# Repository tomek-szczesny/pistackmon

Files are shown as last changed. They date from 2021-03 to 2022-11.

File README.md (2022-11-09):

# PiStackMon

## What is it?

PiStackMon started off as a hardware module for distributing power to multiple stacked Raspberry Pi computers, rathen than handling multiple USB power adapters.

Over time, with its feature list open for new ideas, it grew into a highly integrated, multi purpose board with extended connectivity options.

The most eye catching feature is the live system monitor, with three most basic parameters (Temperature, RAM and CPU) clearly presented on a LED matrix. This helps quickly diagnosing performance bottlenecks by just looking at your cluster. LEDs are driven by a lightweight daemon, *pistackmond*, that compiles and runs on any target architecture.

PiStackMon comes with a variety of extra connectivity features, such as optically isolated outputs, isolated high current switches (up to 6A), dedicated fan output with suitable transistor, not to mention the usual I2C, UART or SPI.

Finally, PiStackMon allows you to power your SBC via GPIO pins, with additional polyfuse protection and a large capacitor, ensuring safe and stable operation. Screw terminals or barrel jack power inputs let you use any 5V power supply you wish, or even daisy chain a few units, thus sharing a common supply.

PiStackMon is compatible with any SBC following the RasPi GPIO layout. 

## Hardware

PiStackMon comes in two varieties, *lite* and *classic*.

### PiStackMon Lite

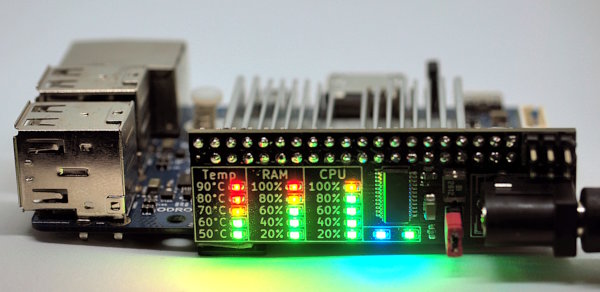
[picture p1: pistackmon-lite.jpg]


By popular demand, a new hardware version has been rolled out, offering the most useful subset of features seen in the Classic design. All mandatory SMD components are placed on top side, so the board may be ordered preassembled by JLCPCB. All required files are available in this repository.

The user is required to solder their own 40-pin socket, power switch pin header and power socket of their choice.

Features include:

- DC power input (either 5mm screw terminal or barrel jack)

- 2.5A Polyfuse protection

- 100uF ceramic capacitor

- Pin header for managing power supply (using a jumper or any other mechanical switch)

- 3x 5-LED indicators of real-time CPU usage, RAM usage and CPU temperature

- +5V LED indicator

- Extra user-programmable LED

- Soldering pads for accesing selected GPIOs:
  
  - I2C1
  
  - UART
  
  - GND, 3V3

- Two 0805 SMD placeholders for optional I2C1 pullup resistors

### PiStackMon Classic

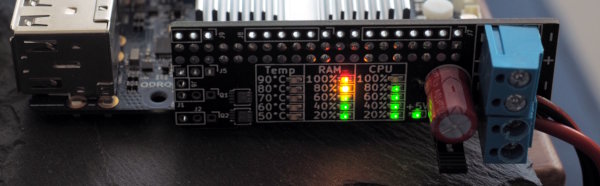
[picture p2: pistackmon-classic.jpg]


The omnipotent, original design with all features available in the project. It is targeted at more advanced users, as no kits or preassembled units are available.

Alternatively, the schematic and KiCAD project files are available for reference. Feel free to modify it to suit your needs!

The design follows strict rules, so PCBs may be obtained for as low as 2 USD per 5 pieces at JLCPCB. 

- Supplying SBCs via screw terminals rather than USB port

- Dual power inputs-outputs allow clean and easy daisy-chaining

- 2.5A self-healing polyfuse protection 

- Bulk capacitor helps preventing transient undervoltage events

- Pin header for managing power supply (using a jumper or any other mechanical switch)

- +5V LED indicator

- 3x 5-LED indicators of real-time CPU usage, RAM usage and CPU temperature

- Auxiliary IOs for your projects:
  
  - SPI0, I2C1 and 1Wire easily accesible through 2.54mm headers
  
  - 1-Wire pullup resistor
  
  - 3-pin header with RC-filtered 3V3 supply for IR sensors
  
  - 2-pin header with 5V and BJT-reinforced low side switch, for PWM fan control
  
  - Two optically isolated outputs, for pulling external logic up or down (>2.5mA)
  
  - Two high-power, isolated low side switches, up to 26V and 6A
  
  - Alternatively, MCP1416s can be used as line drivers directly
  
  - Optical isolation lets you drive external circuits without creating ground loops
  
  - One isolated output and one high-power switch are connected to hardware PWM GPIO pins

- Low profile PCBs allow stacking with spacers as short as 20mm,

- No risk of contact with conductive stack spacers

- Components selected for low cost and relatively easy assembly (One TSSOP24 chip might be tricky)

- Alternative components are listed as well

- Modular design lets you build even cheaper boards without features you don't need

## Software

*pistackmond* is a lightweight daemon that's only purpose is to read system stats and drive PiStackMon LEDs. Additionally, it may be used by external software to drive the user-programmable LED available in PiStackMon Lite.

The recommended way to set up *pistackmond* on a target machine is to build it from source, in a few simple steps explained below. Alternatively, a DEB package may be built and distributed within your cluster.

*pistackmond* runs as a systemd service and has no dependencies outside standard C++ libraries. It has been tested on multiple Linux systems, including those based on Ubuntu, Debian or Arch.

#### Building pistackmond from source

- Log in to your SBC as any user with sudo access. 

- Install `git`, `g++` and `make`:
  
  - Debian, Ubuntu, RasPi OS etc:
    
    `sudo apt install git g++ make`
  
  - Arch, Manjaro and other derivatives:
    
    `sudo pacman -S git gcc make`

- Clone this repository:
  
  `git clone --depth 1 --branch main https://github.com/tomek-szczesny/pistackmon.git`

- Enter sw directory:
  
  - `cd pistackmon/sw`

- List build options to pick the right one for your SBC:
  
  - `make`

- Build pistackmond (Example for Raspberry Pi 4):
  
  - `make rpi4`

- Install and run systemd service
  
  - `sudo make install`

Note that you can change the default-brightness of LED-colors using the make
command, e.g. the following command changes the default 0.35 to 0.25.

    make rpi4 LED_G=0.25

The executable `pistackmond` supports various commandline arguments, see

    pistackmond -h

for a short help. Typically it is used to control the user-led (light version
only):

    pistackmond -u 1
    pistackmond -u 0
    pistackmond -u 0.4

The first command turns the blue user-led on, the second off and the third
turns it on with reduced brightness.

The `-b` option is used as a scaling factor for the overall brightness and
is only valid during service-startup. To set the factor for the service,
edit `/etc/default/pistackmond`.

That's it! PiStackMon should start displaying your computer stats immediately.

#### Creating a DEB-Package

In case you don't want to have a compiler and source code on your
production machines, you can create a deb-package on one system and
install it on multiple other systems.

The recommended procedure is:

```
apt-get -y install checkinstall  # if not already installed
cd pistackmon/sw
make clean                       # in case you don't start from scratch
#edit the `makefile` and replace `PREFIX=/usr/local` with `PREFIX=/usr`
make rpi4
sudo ./make-deb rpi4
```

This will create a package named `pistackmond-rpi4...deb`.

To install this package, run

```
dpkg -i pistackmond-rpi4...deb
sudo systemctl start pistackmond.service
```

## Compatible SBCs

PiStackMon is electrically compatible with all SBCs that follow the RasPi 40-pin GPIO layout. However, explicit support must be implemented in *pistackmond* daemon for that to work.

| SBC | Status | Remarks |
| --- | --- | --- |
| Raspberry Pi 3 | Compatible | |
| Raspberry Pi 4 | Compatible | |
| Odroid N2(+)(L)| Compatible | Powering via PiStackMon is not supported. Any attempt will likely destroy your N2. |
| Odroid C1(+) | Compatible | Temperature sensing not confirmed. OS must export CPU temperature to the following file: `/sys/devices/virtual/thermal/thermal_zone0/temp` |
| Odroid C2 | Compatible | Powering via PiStackMon may be possible - not tested, proceed with caution. |
| Odroid M1 | Compatible | Powering via PiStackMon is not supported. Any attempt will likely destroy your M1. |

Limited amount of free PiStackMon samples is available for testers and contributors for new platforms. Open an Issue to get in touch!

# Disclaimer

This hardware and software is provided as-is.
All hardware and software presented in this repository may pose hazard to humans, animals, plants, fungi, ghosts, spirits and hardware, and is not guaranteed to work at all.
DO NOT ATTEMPT TO MAKE ANY USE OF FILES PROVIDED IN THIS REPOSITORY.

Users agree to take full responsibility for their actions involving files in this repository.
Ask an expert before you mess with stuff you don't understand.

# 

# Building PistackMon Classic

This chapter will definitely need some love, but for now just be sure to follow a few guidelines off the top of my head:

- Decide which features you need or not. As a rule of thumb, you may ignore any boxed part of a schematic independently.
- Check the datasheet of your LEDs or experiment to determine what is the optimal driving current for them. Some LEDs need 1mA, some 10mA. There are no recommended LEDs for PiStackMon.
- If different colors of your LEDs of choice have different intensities, don't worry, there are const values in the code to compensate for that.
- "NM" resistors are simply Not Mounted - leave these places empty, unlesss you want to hack PiStackMon for other purposes.
- Before you do anything, just remember that 40-pin connector should be mounted as the very last component, after you make sure everything else works. Consider it a permanent component, because removing it is indeed a pain in the rectum.
- Mount everything you plan to include, except 40-pin connector and C1. Power up your SBC using its original power input. You may test PiStackMon by carefully connecting it to SBC's GPIO header directly, and applying some tension to ensure proper connection. It is a good idea to check if all LEDs work correctly and that you picked the right LED currents.
- After soldering, make sure you clean your board _very carefully_ from any traces of flux, especially under and around the LED driver chip. Dip it in pure alcohol for an hour if you have to. Failing to do so may make some LEDs glow even though these are supposed to be off.
- Place a tiny heatsink on a low side high-power switch MOSFET if you plan to thrash the living hell out of it.

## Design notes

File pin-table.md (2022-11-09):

Pin-Table
=========

This table just documents the pins for the various supported boards.
Numbers in parenthesis are libgpiod-line numbers.

Pin   |Physical | Pi3/Pi4 |  N2(+)(L) |   C1(+)       |  C2  |  M1 (numbers to be verified) |
------|---------|---------|-----------|---------------|------|------------------------------|
DATA  |      11 |      17 |  X.3 (69) |  88  Y.8 (23) | X.19 | 0C.0 (16)                    |
CLK   |      13 |      27 |  X.4 (70) | 116 X.19 (15) | X.11 | 0C.1 (17)                    |
LATCH |      15 |      22 |  X.7 (73) | 115 X.18 (14) | X.9  | 3B.2 (106)                   |
BLANK |      22 |      25 |  X.2 (68) | 103 X.6  ()   | X.3  | 3D.1 (121)                   |

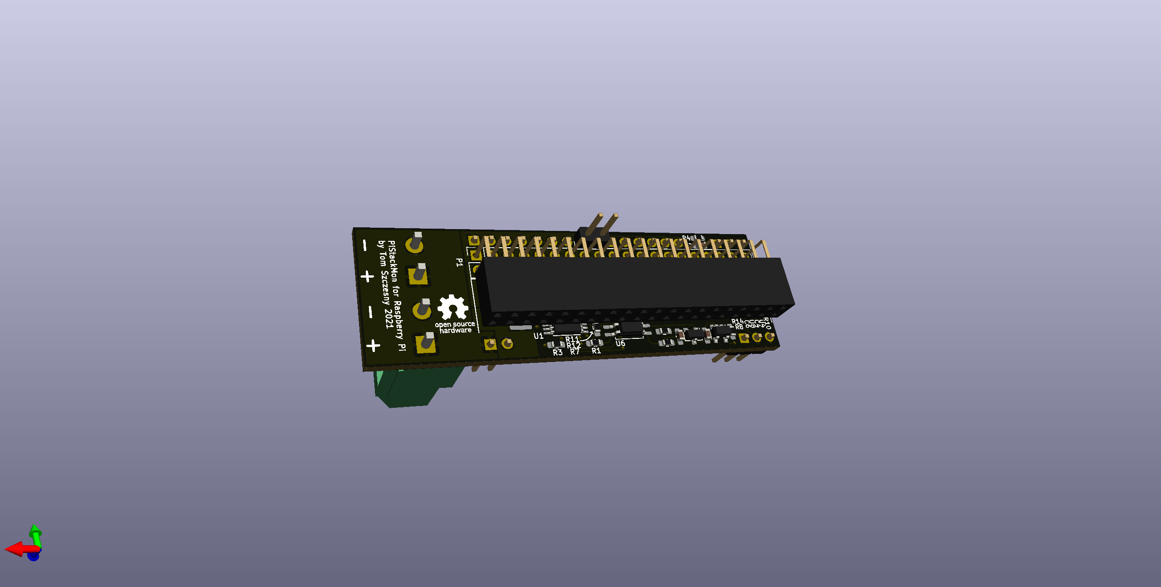
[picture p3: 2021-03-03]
hw/classic/pdfs/PiStackMon_back.png

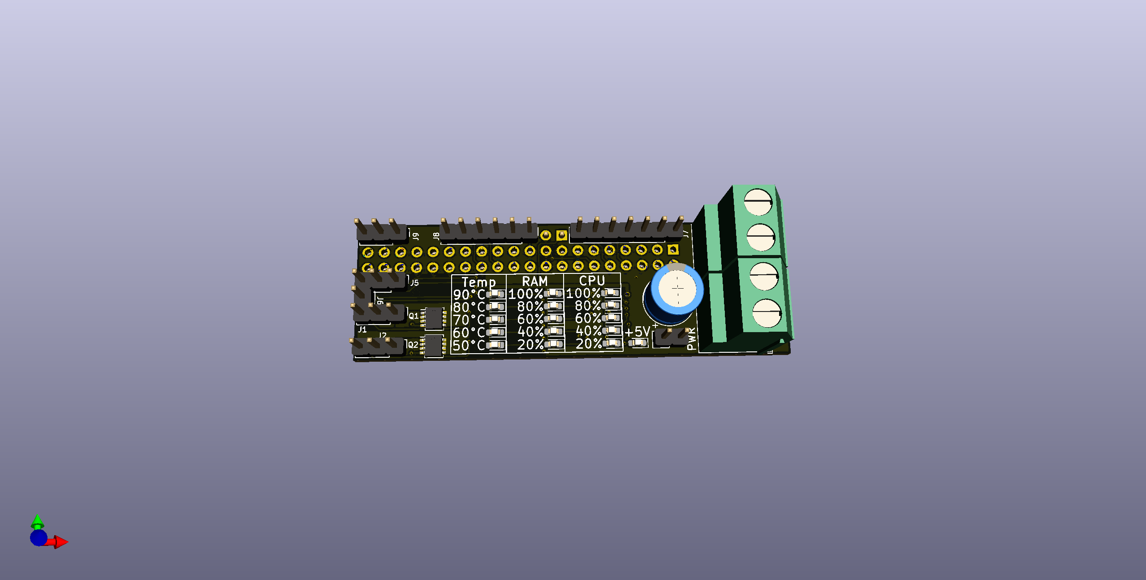
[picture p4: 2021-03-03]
hw/classic/pdfs/PiStackMon.png

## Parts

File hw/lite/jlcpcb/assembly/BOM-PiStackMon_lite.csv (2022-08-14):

Comment | Designator | Footprint | LCSC
TLC59282DBQR | U1 | SSOP-24_3.9x8.7mm_P0.635mm | C129352
100u 6.3V | C1 | C_1206_3216Metric | C15008
100n | C2 | C_0402_1005Metric | C1525
1k8 | R3 | R_0603_1608Metric | C4177
27k | R2 | R_0603_1608Metric | C22967
3k3 | R5 | R_0402_1005Metric | C25890
SMD1812B260TF/12 | F1 | Fuse_1812_4532Metric | C269147
Y | D13,D5,D9 | LED_0603_1608Metric | C72038
B | D17 | LED_0603_1608Metric | C72041
G | D1,D14,D15,D16,D2,D3,D4,D6,D7,D8 | LED_0603_1608Metric | C72043
R | D10,D11,D12 | LED_0603_1608Metric | C72044

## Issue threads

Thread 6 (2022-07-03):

pistackmond crashes immediately after previous instance terminated with sigkill

tomek-szczesny, 2022-07-03:
After pistackmond has been terminated non-gracefully (with sigkill), it appears the shared memory file still exists and stands in the way.
Sudoer can remove this file and later everything works as expected.

I'm not sure whether pistackmond should check if shared memory file exists and if so, maybe try deleting it. If that succeeds, then it means there is no other pistackmond process that keeps this file open. I'm just speculating here and would appreciate your input, @bablokb. Thanks!

```
mctom@odroidm1:~/git/pistackmon/sw$ sudo systemctl status pistackmond.service
● pistackmond.service - PiStackMon Daemon
     Loaded: loaded (/etc/systemd/system/pistackmond.service; enabled; vendor preset: enable>
     Active: failed (Result: exit-code) since Sun 2022-07-03 13:52:14 CEST; 31s ago
    Process: 3353 ExecStart=/usr/local/sbin/pistackmond (code=exited, status=3)
   Main PID: 3353 (code=exited, status=3)

lip 03 13:52:14 odroidm1 systemd[1]: Started PiStackMon Daemon.
lip 03 13:52:14 odroidm1 pistackmond[3353]: shm_open failed: File exists
lip 03 13:52:14 odroidm1 systemd[1]: pistackmond.service: Main process exited, code=exited, >
lip 03 13:52:14 odroidm1 systemd[1]: pistackmond.service: Failed with result 'exit-code'.
...skipping...
● pistackmond.service - PiStackMon Daemon
     Loaded: loaded (/etc/systemd/system/pistackmond.service; enabled; vendor preset: enable>
     Active: failed (Result: exit-code) since Sun 2022-07-03 13:52:14 CEST; 31s ago
    Process: 3353 ExecStart=/usr/local/sbin/pistackmond (code=exited, status=3)
   Main PID: 3353 (code=exited, status=3)

lip 03 13:52:14 odroidm1 systemd[1]: Started PiStackMon Daemon.
lip 03 13:52:14 odroidm1 pistackmond[3353]: shm_open failed: File exists
lip 03 13:52:14 odroidm1 systemd[1]: pistackmond.service: Main process exited, code=exited, >
lip 03 13:52:14 odroidm1 systemd[1]: pistackmond.service: Failed with result 'exit-code'.
```

bablokb, 2022-07-03:
Oh yes. The service creates the shared memory and therefore is also responsible for the deletion. I will fix this. The signal-handler are already in place.

bablokb, 2022-07-03:
Should be fixed with commit 491d5954197e8289864cbb2f41f7fcfb871be11b

bablokb, 2022-07-05:
> I don't think we should handle more signals, actually SIGKILL was very handy to kill pistackmond when I made it to loop infinitely by mistake. All the other signals got caught and waited for PWM thread to finish, which unfortunately was looped forever.

We can't trap SIGKILL anyhow.

> Ideally, pistackmond should give up and exit if it finds evidence of another instance already running. Otherwise, create the shared memory file or reuse the existing one (with any value already stored in there). I hope you agree this is the best scenario. :)
>
> In bash world, I'd check if this command returns more than "1": `ps aux | grep pistackmond | grep root | wc -l` But perhaps more elegant solution exists in C++, can't tell really.

I think there is something more elegant in bash too ;-) (e.g. using -u and -C options of ps). But the main point is: does it make sense to blow up the code to catch a border-case which typically will only happen on a developer-machine?

So basically we have a few options:

  - *No change to the code, i.e. do nothing*. In this case pistackmond just won't start a second time because it assumes a running service. Normally this should be correct. If root is SIGKILLing the process, root should also remove the shm.
  - *Reuse the existing shm*. This could lead to two running services, but only if at least one of the pistackmond-executables is started manually. If you start via systemctl this should always be safe.

The caveat of the second option is the case where a user wants to set the user-led and just forgets to add the necessary parameter. But since we want to add cmdline options anyhow, we could add the option `-s` as a prereq for starting the service.

So I would suggest to leave the code as is for now. After adding cmdline-options, then we could switch to reusing the shm if it already exists. I feel no pity if someone afterwards explicitly starts the service twice.

tomek-szczesny, 2022-07-05:
Yeah, I guess you're right, it's not critical by any means. If it was fixable with 5 lines of code that would be worth consideration, but otherwise I guess we can assume the service protects against running two instances.

> The caveat of the second option is the case where a user wants to set the user-led and just forgets to add the necessary parameter.

If run as non-root user it will crash anyway. There is a TODO in the code to catch that and yell at the user instead ;)

bablokb, 2022-07-05:
Good. So I will now merge the user_led branch into main, then start with a new branch for the cmdline-options. Once this is in place I will switch the behavior to reuse the shm.

tomek-szczesny, 2022-07-05:
Excellent.
I'm leaving for Masters of Rock festival tomorrow morning so I won't be too responsive for the following week. :)

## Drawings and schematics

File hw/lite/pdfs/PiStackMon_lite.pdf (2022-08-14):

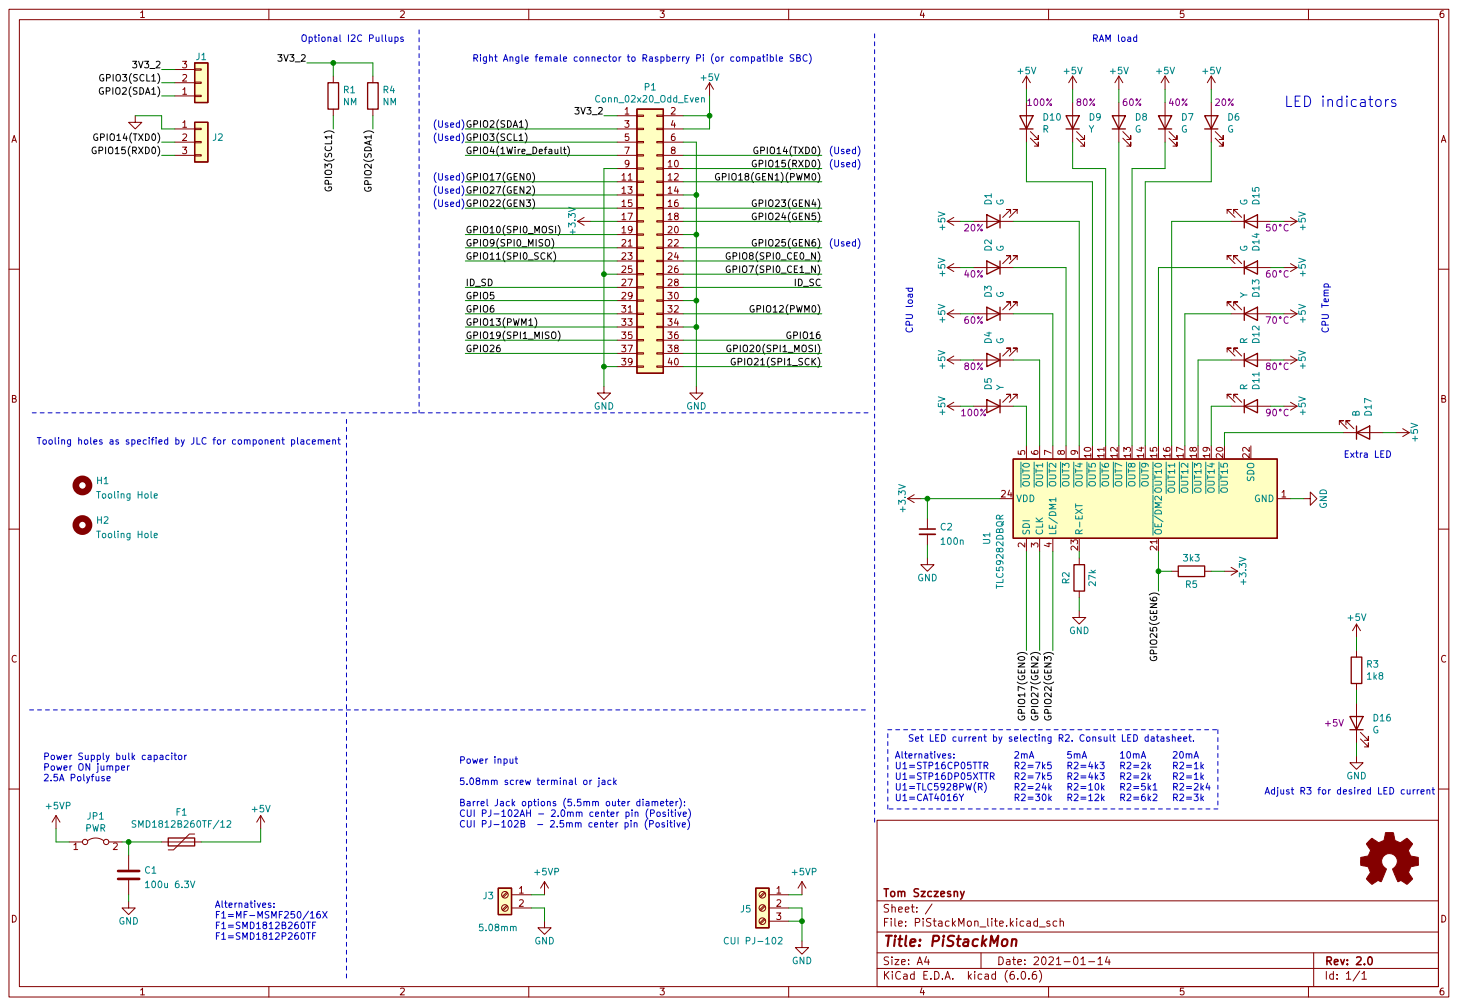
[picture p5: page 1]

Tooling holes as specified by JLC for component placement

Set LED current by selecting R2. Consult LED datasheet.
5mA R2=4k3 R2=4k3 R2=10k R2=12k Alternatives: U1=STP16CP05TTR

Power Supply bulk capacitor
Power ON jumper
2.5A Polyfuse

5.08mm screw terminal or jack

Barrel Jack options (5.5mm outer diameter):
CUI PJ-102AH - 2.0mm center pin (Positive)

File: PiStackMon_lite.kicad_sch Sheet: / Tom Szczesny

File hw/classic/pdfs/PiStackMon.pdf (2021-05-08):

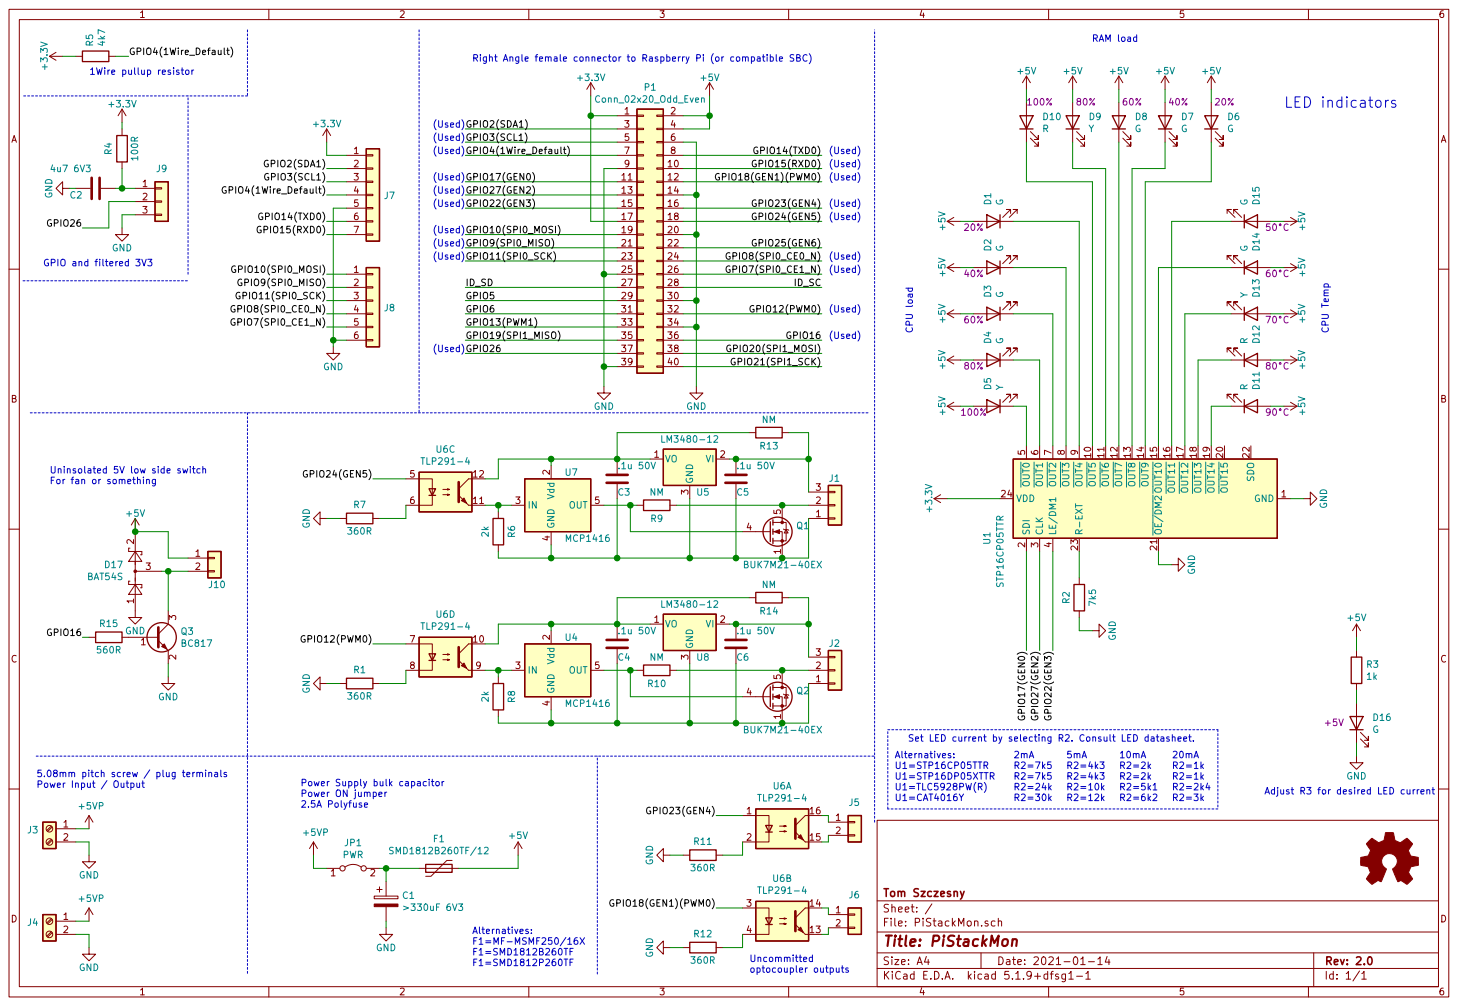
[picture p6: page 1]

Right Angle female connector to Raspberry Pi (or compatible SBC)
GPIO2(SDA1) GPIO6 GPIO5
GPIO3(SCL1)
GPIO4(1Wire_Default)

(Used) GPIO and filtered 3V3

(Used) Uninsolated 5V low side switch For fan or something

5.08mm pitch screw / plug terminals

Power Supply bulk capacitor
Power ON jumper
2.5A Polyfuse

Adjust R3 for desired LED current

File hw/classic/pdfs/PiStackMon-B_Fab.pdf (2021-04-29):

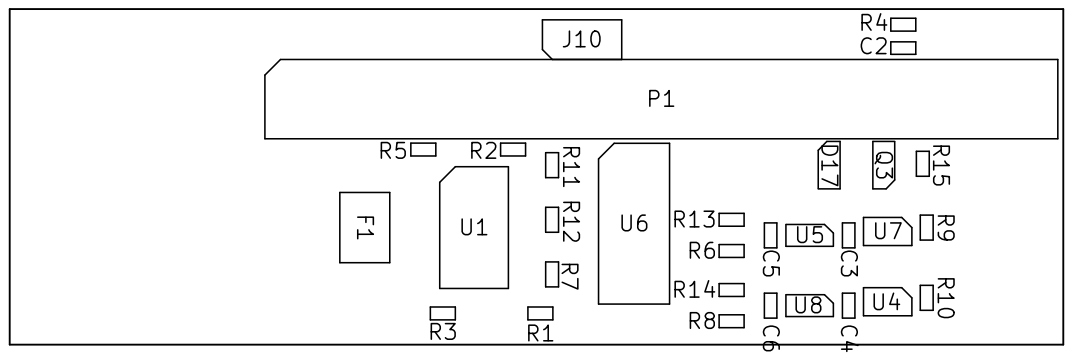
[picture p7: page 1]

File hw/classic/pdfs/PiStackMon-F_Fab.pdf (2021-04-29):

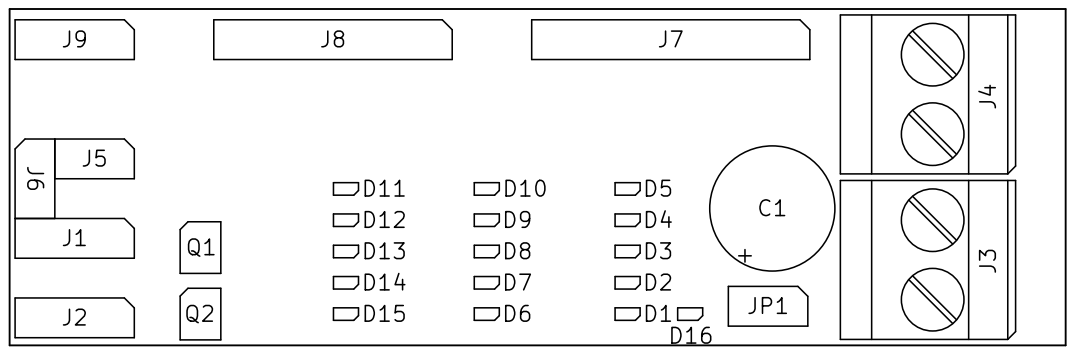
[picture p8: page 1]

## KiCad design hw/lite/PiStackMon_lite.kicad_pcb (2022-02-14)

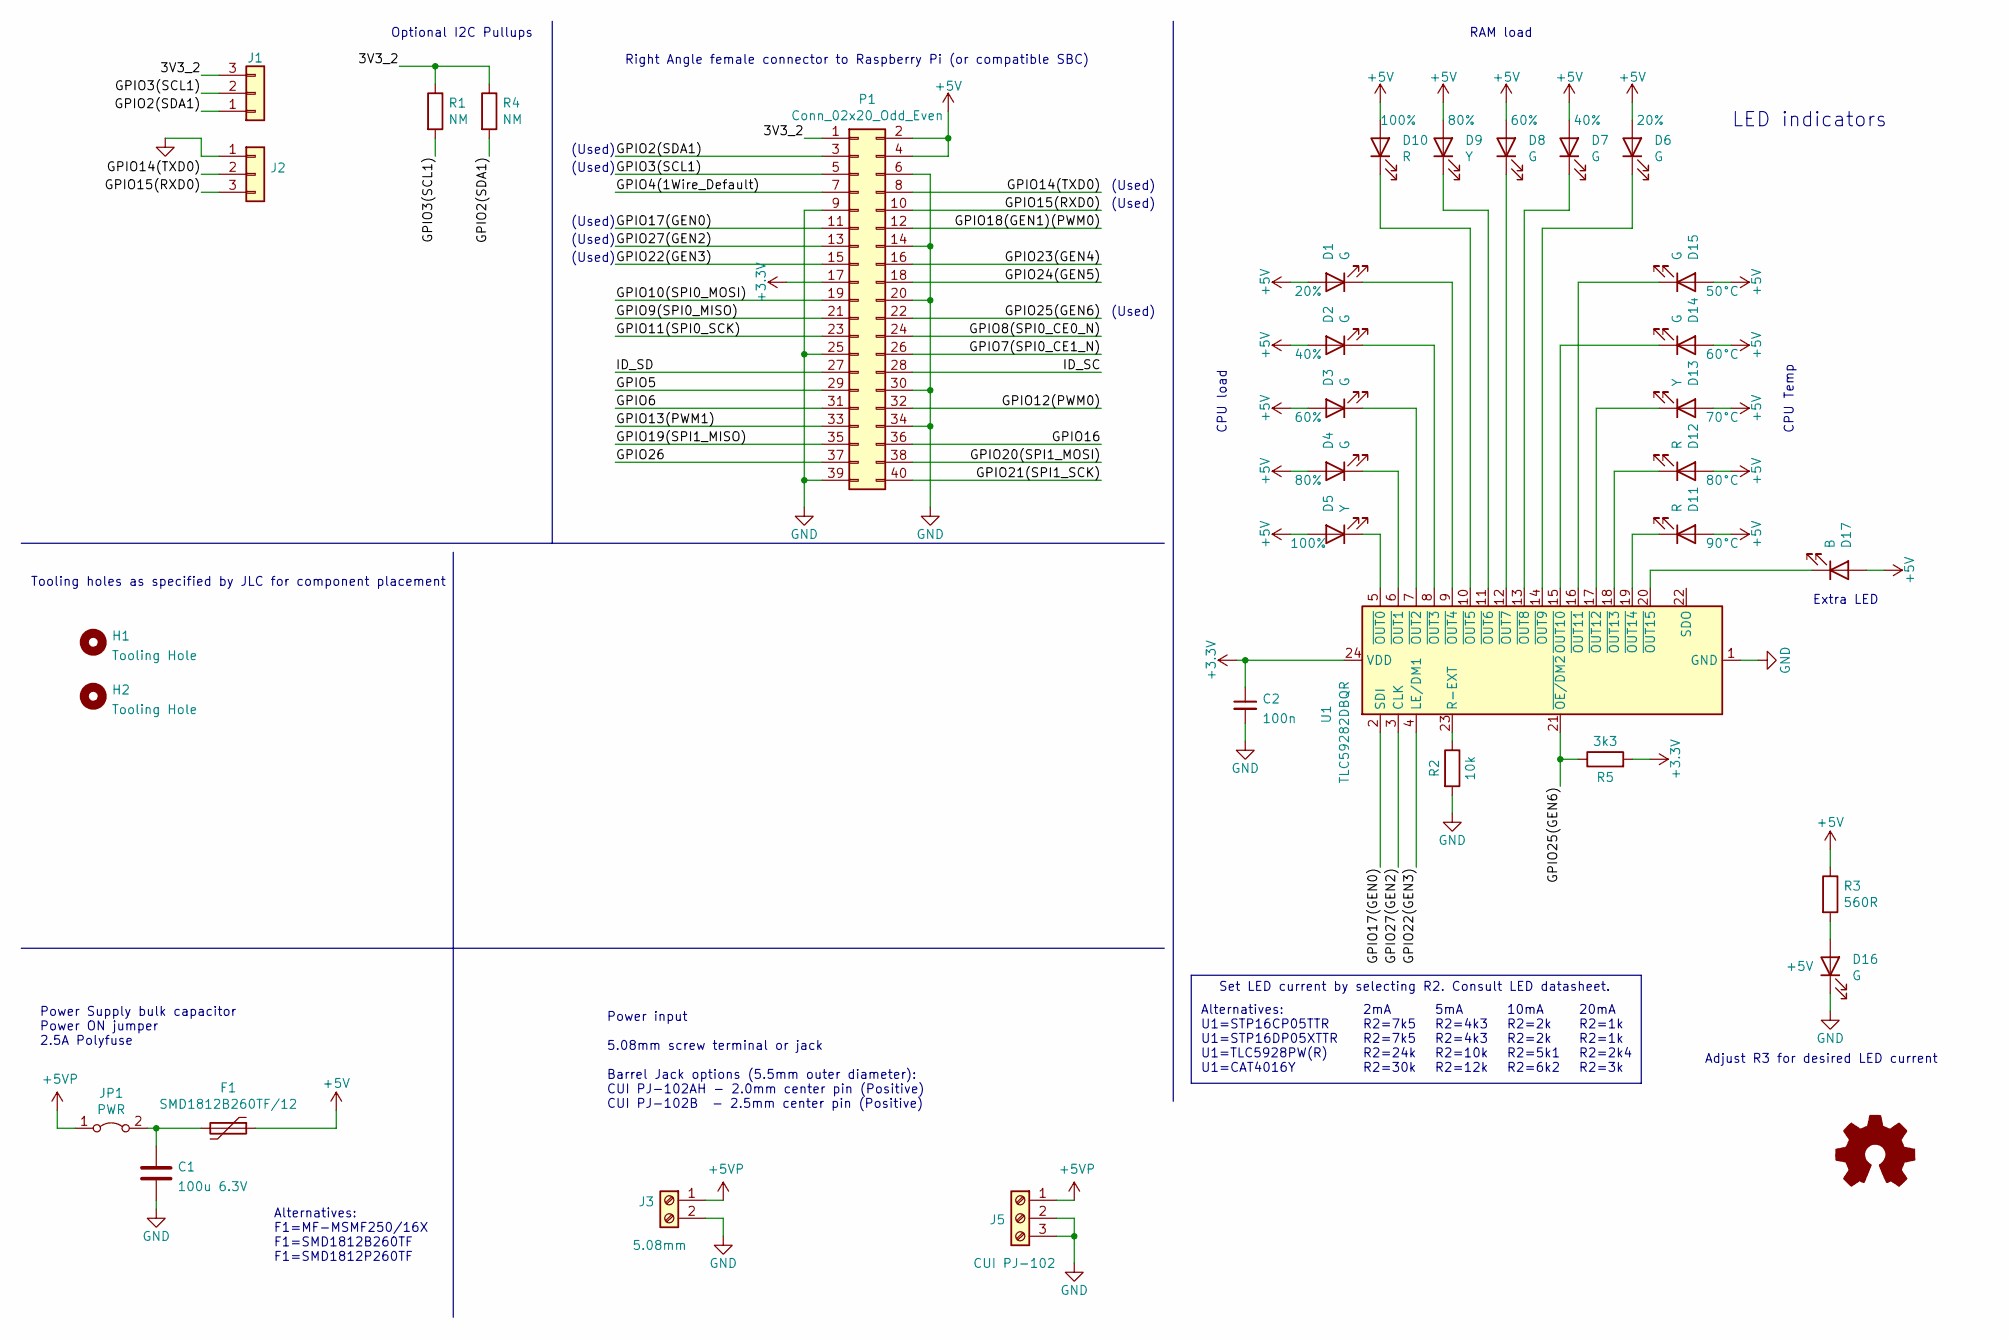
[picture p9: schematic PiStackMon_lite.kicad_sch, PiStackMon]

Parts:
C1: 100u 6.3V; C_1206_3216Metric; JLC 1206
C2: 100n; C_0402_1005Metric; LCSC C1525
D1, D2, D3, D4, D6, D7, D8, D14, D15, D16: G; LED_0603_1608Metric; LCSC C72043
D5, D9, D13: Y; LED_0603_1608Metric; LCSC C72038
D10, D11, D12: R; LED_0603_1608Metric; LCSC C72044
D17: B; LED_0603_1608Metric; LCSC C72041
F1: SMD1812B260TF/12; Fuse_1812_4532Metric; LCSC C269147
H1, H2: Tooling Hole
J1, J2: Conn_01x03; PinHeader_1x03_P2.54mm_Vertical
J3: 5.08mm; TerminalBlock_Phoenix_MKDS-3-2-5.08_1x02_P5.08mm_Horizontal
J5: CUI PJ-102; BarrelJack_CUI_PJ-102AH_Horizontal
JP1: PWR; PinHeader_1x02_P2.54mm_Vertical
LOGO1: Logo_Open_Hardware_Small; OSHW-Logo_5.7x6mm_SilkScreen
P1: Conn_02x20_Odd_Even; PinSocket_2x20_P2.54mm_Vertical
R1, R4: NM; R_0805_2012Metric_Pad1.20x1.40mm_HandSolder
R2: 10k; R_0603_1608Metric; LCSC C25804
R3: 560R; R_0603_1608Metric; LCSC C23204
R5: 3k3; R_0402_1005Metric; LCSC C25890
U1: TLC59282DBQR; SSOP-24_3.9x8.7mm_P0.635mm; LCSC C129352

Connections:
+3V3: C2.1, P1.17, R5.2, U1.24 (VDD)
+5V: D1.2 (A), D2.2 (A), D3.2 (A), D4.2 (A), D5.2 (A), D6.2 (A), D7.2 (A), D8.2 (A), D9.2 (A), D10.2 (A), D11.2 (A), D12.2 (A), D13.2 (A), D14.2 (A), D15.2 (A), D17.2 (A), F1.1, P1.2, P1.4, R3.1
+5VP: J3.1, J5.1, JP1.1 (A)
/3V3_2: J1.3, P1.1, R1.1, R4.1
/GPIO2(SDA1): J1.1, P1.3, R4.2
/GPIO3(SCL1): J1.2, P1.5, R1.2
/GPIO4(1Wire_Default): P1.7
/GPIO5: P1.29
/GPIO6: P1.31
/GPIO7(SPI0_CE1_N): P1.26
/GPIO8(SPI0_CE0_N): P1.24
/GPIO9(SPI0_MISO): P1.21
/GPIO10(SPI0_MOSI): P1.19
/GPIO11(SPI0_SCK): P1.23
/GPIO12(PWM0): P1.32
/GPIO13(PWM1): P1.33
/GPIO14(TXD0): J2.2, P1.8
/GPIO15(RXD0): J2.3, P1.10
/GPIO16: P1.36
/GPIO17(GEN0): P1.11, U1.2 (SDI)
/GPIO18(GEN1)(PWM0): P1.12
/GPIO19(SPI1_MISO): P1.35
/GPIO20(SPI1_MOSI): P1.38
/GPIO22(GEN3): P1.15, U1.4 (LE/DM1)
/GPIO23(GEN4): P1.16
/GPIO24(GEN5): P1.18
/GPIO25(GEN6): P1.22, R5.1, U1.21 (~OE/DM2)
/GPIO26: P1.37
/GPIO27(GEN2): P1.13, U1.3 (CLK)
/ID_SC: P1.28
/ID_SD: P1.27
GND: C1.2, C2.2, D16.1 (K), J2.1, J3.2, J5.2, J5.3, P1.6, P1.9, P1.14, P1.20, P1.25, P1.30, P1.34, P1.39, R2.2, U1.1 (GND)
unnamed: C1.1, F1.2, JP1.2 (B)
unnamed: D1.1 (K), U1.9 (~OUT4)
unnamed: D2.1 (K), U1.8 (~OUT3)
unnamed: D3.1 (K), U1.7 (~OUT2)
unnamed: D4.1 (K), U1.6 (~OUT1)
unnamed: D5.1 (K), U1.5 (~OUT0)
unnamed: D6.1 (K), U1.14 (~OUT9)
unnamed: D7.1 (K), U1.13 (~OUT8)
unnamed: D8.1 (K), U1.12 (~OUT7)
unnamed: D9.1 (K), U1.11 (~OUT6)
unnamed: D10.1 (K), U1.10 (~OUT5)
unnamed: D11.1 (K), U1.19 (~OUT14)
unnamed: D12.1 (K), U1.18 (~OUT13)
unnamed: D13.1 (K), U1.17 (~OUT12)
unnamed: D14.1 (K), U1.15 (~OUT10)
unnamed: D15.1 (K), U1.16 (~OUT11)
unnamed: D16.2 (A), R3.2
unnamed: D17.1 (K), U1.20 (~OUT15)
unnamed: R2.1, U1.23 (R-EXT)

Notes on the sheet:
(Used)
CPU load
Right Angle female connector to Raspberry Pi (or compatible SBC)
Set LED current by selecting R2. Consult LED datasheet.
Power Supply bulk capacitor Power ON jumper 2.5A Polyfuse
CPU Temp
Extra LED
LED indicators
Tooling holes as specified by JLC for component placement
2mA R2=7k5 R2=7k5 R2=24k R2=30k
20mA R2=1k R2=1k R2=2k4 R2=3k
Alternatives: U1=STP16CP05TTR U1=STP16DP05XTTR U1=TLC5928PW(R) U1=CAT4016Y
10mA R2=2k R2=2k R2=5k1 R2=6k2
5mA R2=4k3 R2=4k3 R2=10k R2=12k
Adjust R3 for desired LED current
Alternatives: F1=MF-MSMF250/16X F1=SMD1812B260TF F1=SMD1812P260TF
Power input 5.08mm screw terminal or jack Barrel Jack options (5.5mm outer diameter): CUI PJ-102AH - 2.0mm center pin (Positive) CUI PJ-102B - 2.5mm center pin (Positive)
Optional I2C Pullups
RAM load

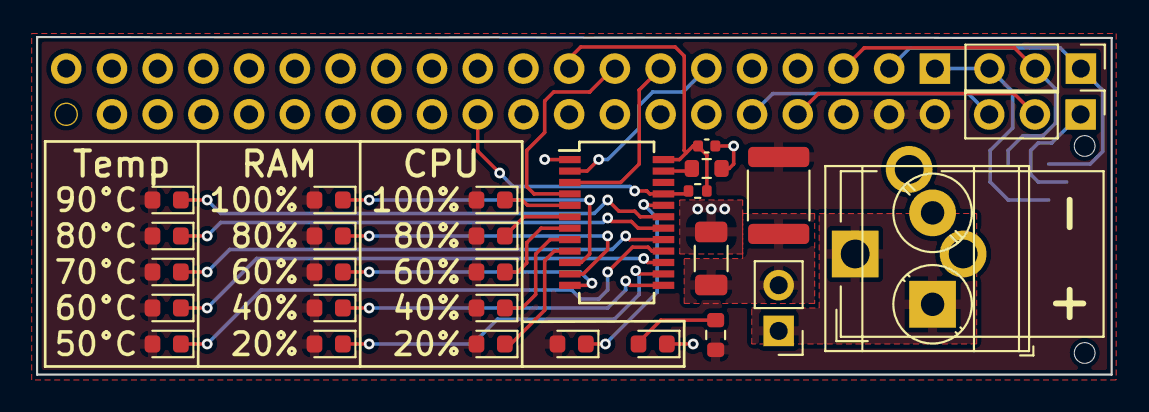
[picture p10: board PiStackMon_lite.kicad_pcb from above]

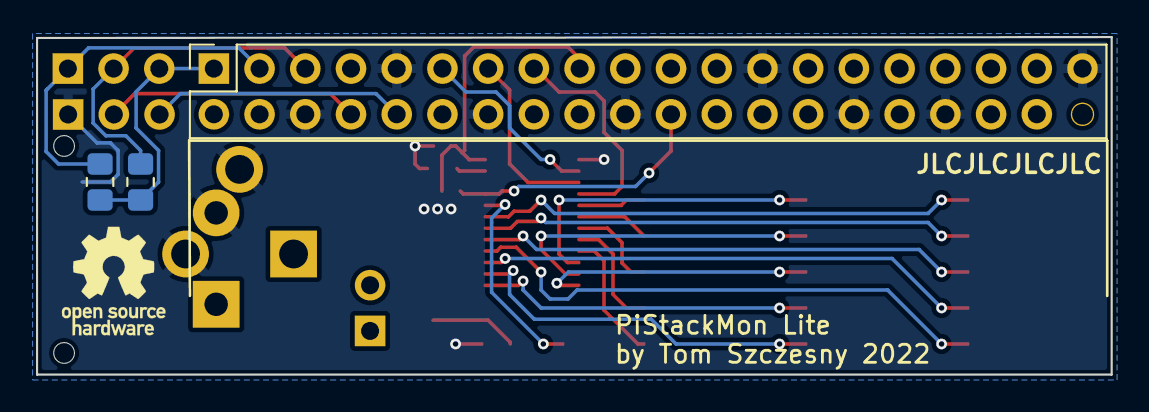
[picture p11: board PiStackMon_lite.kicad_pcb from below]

Board: 2 copper layers, 59.7 x 18.8 mm, 35 parts (4 on the bottom side), 32 nets.

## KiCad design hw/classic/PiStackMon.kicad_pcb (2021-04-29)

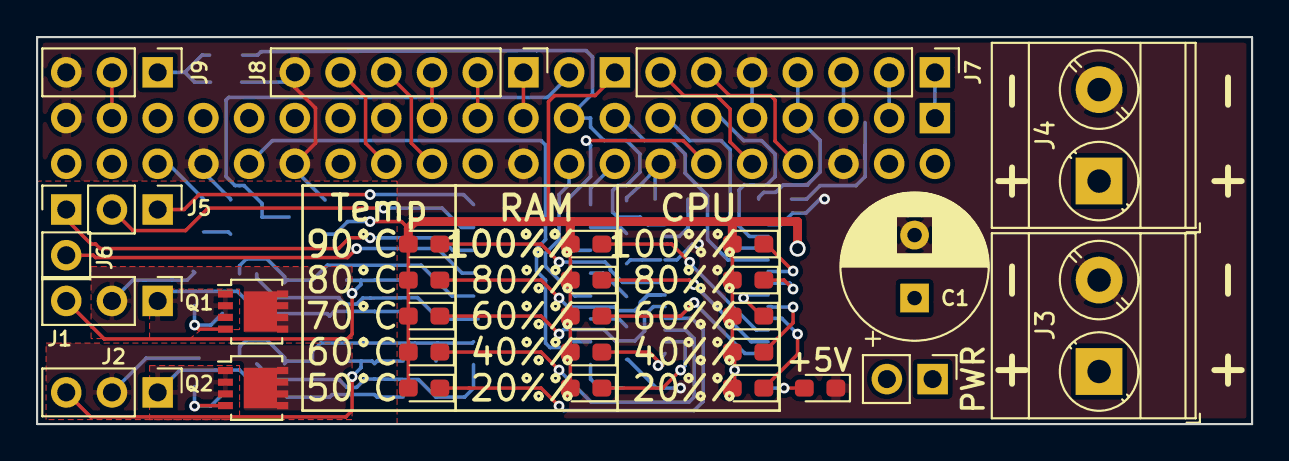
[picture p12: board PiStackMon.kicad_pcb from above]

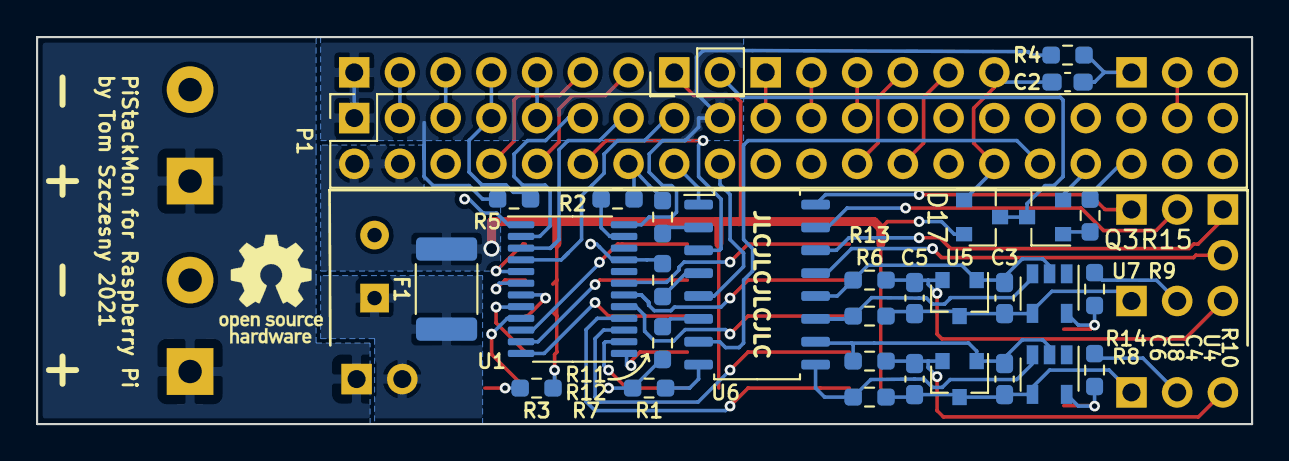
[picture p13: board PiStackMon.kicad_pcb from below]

Board: 2 copper layers, 67.5 x 21.5 mm, 61 parts (32 on the bottom side), 64 nets.

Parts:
C1: >330uF 6V3; CP_Radial_D8.0mm_P3.50mm
C2: 4u7 6V3; C_0603_1608Metric_Pad1.08x0.95mm_HandSolder
C3, C4, C5, C6: .1u 50V; C_0603_1608Metric_Pad1.08x0.95mm_HandSolder
D1, D2, D3, D4, D6, D7, D13, D14, D15, D16: G; LED_0603_1608Metric_Pad1.05x0.95mm_HandSolder
D5, D8, D9, D12: Y; LED_0603_1608Metric_Pad1.05x0.95mm_HandSolder
D10, D11: R; LED_0603_1608Metric_Pad1.05x0.95mm_HandSolder
D17: BAT54S; SOT-23
F1: SMD1812B260TF/12; Fuse_1812_4532Metric_Pad1.30x3.40mm_HandSolder
J1, J2, J9: Conn_01x03; PinHeader_1x03_P2.54mm_Vertical
J3, J4: Screw_Terminal_01x02; TerminalBlock_Phoenix_MKDS-3-2-5.08_1x02_P5.08mm_Horizontal
J5, J6, J10: Conn_01x02; PinHeader_1x02_P2.54mm_Vertical
J7: Conn_01x07; PinHeader_1x07_P2.54mm_Vertical
J8: Conn_01x05; PinHeader_1x06_P2.54mm_Vertical
JP1: PWR; PinHeader_1x02_P2.54mm_Vertical
LOGO1: Logo_Open_Hardware_Small; OSHW-Logo_5.7x6mm_SilkScreen
P1: Conn_02x20_Odd_Even; PinSocket_2x20_P2.54mm_Vertical
Q1, Q2: BUK7M21-40EX; LFPAK33
Q3: BC817; SOT-23
R1, R7, R11, R12: 360R; R_0603_1608Metric_Pad0.98x0.95mm_HandSolder
R2: 7k5; R_0603_1608Metric_Pad0.98x0.95mm_HandSolder
R3: 1k; R_0603_1608Metric_Pad0.98x0.95mm_HandSolder
R4: 100R; R_0603_1608Metric_Pad0.98x0.95mm_HandSolder
R5: 4k7; R_0603_1608Metric_Pad0.98x0.95mm_HandSolder
R6, R8: 2k; R_0603_1608Metric_Pad0.98x0.95mm_HandSolder
R9, R10, R13, R14: NM; R_0603_1608Metric_Pad0.98x0.95mm_HandSolder
R15: 560R; R_0603_1608Metric_Pad0.98x0.95mm_HandSolder
U1: STP16CP05TTR; TSSOP-24_4.4x7.8mm_P0.65mm
U4, U7: MCP1416; SOT-23-5
U5, U8: LM3480-12; SOT-23
U6: TLP291-4; SOIC-16_4.55x10.3mm_P1.27mm

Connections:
+3V3: J7.1, P1.1, P1.17, R4.2, R5.1, U1.24
+5V: D1.2, D2.2, D3.2, D4.2, D5.2, D6.2, D7.2, D8.2, D9.2, D10.2, D11.2, D12.2, D13.2, D14.2, D15.2, D17.2, F1.1, J10.1, P1.2, P1.4, R3.1
+5VP: J3.1, J4.1, JP1.1
/GPIO2(SDA1): J7.2, P1.3
/GPIO3(SCL1): J7.3, P1.5
/GPIO4(1Wire_Default): J7.4, P1.7, R5.2
/GPIO7(SPI0_CE1_N): J8.5, P1.26
/GPIO8(SPI0_CE0_N): J8.4, P1.24
/GPIO9(SPI0_MISO): J8.2, P1.21
/GPIO10(SPI0_MOSI): J8.1, P1.19
/GPIO11(SPI0_SCK): J8.3, P1.23
/GPIO12(PWM0): P1.32, U6.7
/GPIO14(TXD0): J7.6, P1.8
/GPIO15(RXD0): J7.7, P1.10
/GPIO16: P1.36, R15.1
/GPIO17(GEN0): P1.11, U1.2
/GPIO18(GEN1)(PWM0): P1.12, U6.3
/GPIO22(GEN3): P1.15, U1.4
/GPIO23(GEN4): P1.16, U6.1
/GPIO24(GEN5): P1.18, U6.5
/GPIO26: J9.2, P1.37
/GPIO27(GEN2): P1.13, U1.3
GND: C1.2, C2.2, D16.1, D17.1, J3.2, J4.2, J7.5, J8.6, J9.3, P1.6, P1.9, P1.14, P1.20, P1.25, P1.30, P1.34, P1.39, Q3.2, R1.1, R2.2, R7.1, R11.1, R12.1, U1.1, U1.21
unnamed: C1.1, F1.2, JP1.2
unnamed: C2.1, J9.1, R4.1
unnamed: C3.1, R13.2, U5.1, U6.12, U7.2
unnamed: C3.2, C5.2, J1.1, Q1.1, Q1.2, Q1.3, R6.2, U5.3, U7.4
unnamed: C4.1, R14.2, U4.2, U6.10, U8.1
unnamed: C4.2, C6.2, J2.1, Q2.1, Q2.2, Q2.3, R8.2, U4.4, U8.3
unnamed: C5.1, J1.3, R13.1, U5.2
unnamed: C6.1, J2.3, R14.1, U8.2
unnamed: D1.1, U1.9
unnamed: D2.1, U1.8
unnamed: D3.1, U1.7
unnamed: D4.1, U1.6
unnamed: D5.1, U1.5
unnamed: D6.1, U1.14
unnamed: D7.1, U1.13
unnamed: D8.1, U1.12
unnamed: D9.1, U1.11
unnamed: D10.1, U1.10
unnamed: D11.1, U1.19
unnamed: D12.1, U1.18
unnamed: D13.1, U1.17
unnamed: D14.1, U1.15
unnamed: D15.1, U1.16
unnamed: D16.2, R3.2
unnamed: D17.3, J10.2, Q3.3
unnamed: J1.2, Q1.5, R9.1
unnamed: J2.2, Q2.5, R10.1
unnamed: J5.1, U6.16
unnamed: J5.2, U6.15
unnamed: J6.1, U6.14
unnamed: J6.2, U6.13
unnamed: Q1.4, R9.2, U7.5
unnamed: Q2.4, R10.2, U4.5
unnamed: Q3.1, R15.2
unnamed: R1.2, U6.8
unnamed: R2.1, U1.23
unnamed: R6.1, U6.11, U7.3
unnamed: R7.2, U6.6
unnamed: R8.1, U4.3, U6.9
unnamed: R11.2, U6.2
unnamed: R12.2, U6.4

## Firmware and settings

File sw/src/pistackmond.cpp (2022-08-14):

// -------------------------------------------------------------------------
// Main application pistackmond
//
// Website: https://github.com/tomek-szczesny/pistackmon
// Authors: Tomek Szczesny, Bernhard Bablok
// License: GPL3
// -------------------------------------------------------------------------

#include <bitset>
#include <chrono>
#include <cmath>
#include <fstream>
#include <mutex>
#include <signal.h>
#include <iostream>
#include <sstream>
#include <string>
#include <cstring>
#include <cstdio>
#include <thread>
#include <vector>

#include <fcntl.h>	// open()
#include <unistd.h>	// close(), getopt()
#include <sys/mman.h>   // mmap()
#include <sys/stat.h>   // fchmod()
#include <pthread.h>	// pthread_setschedparam()

#include "gpio.h"       // this is a makefile-generated file (link)

using namespace std::chrono_literals;

//=========================== floatLP CLASS ====================================
// A float with low pass filter built in

class floatLP {
	// Acts like a float variable, but internally
	// filters its contents every time it is updated.
	// Must be updated at the same rate to be effective.

	private:
	float z = 0;			// The variable
	float alpha = 1;		// Smoothing factor

	public:

	// z - initial value
	// tau - time constant [s]
	// freq - sampling frequency
	floatLP(float tau, float freq, float z = 0) {
		this->z = z;
		this->alpha = 1 - (std::exp(-1/(freq * tau)));
	}

	floatLP operator=(float z0) {
		z = (alpha * z0) + ((1 - alpha) * z);
		return *this;
	}

	float f() { return z; }

};

//=================================== CONSTS ===================================

// Data refreshing rate
const float refresh_rate = 10;				// Hz
const std::chrono::microseconds refresh_period =
	std::chrono::microseconds(static_cast<uint32_t>(1000000/refresh_rate));

// Refresh divider - the actual data sampling is performed only once in ref_div,
// although data smoothing is performed on every refresh cycle.
const int ref_div = 5;

// LSB period of a PWM driver.
// Generally should be kept under 20ms/(2^pwm_res) for PWM operation above 50Hz
// for the LED intensity to appear smooth.
// Smaller values are possible at the expense of CPU load and accuracy.
// Values under 10us are not recommended due to thread sleep accuracy.
// For mathematical consistency it should be an integer, but you do you.
const float pwm_lsb_period = 50;			// [us]

// bit depth of PWM LED driver (2-16)
const int pwm_res = 8;

// Layout vectors, containing positions of each LED in LED driver register
const std::vector<int> cpu_layout = {4, 3, 2, 1, 0};
const std::vector<int> ram_layout = {9, 8, 7, 6, 5};
const std::vector<int> temp_layout = {11, 10, 12, 13, 14};
const std::vector<int> user_layout = {15};

// Led intensities adjusted by color 
// Depending on LED make and model, some colors might appear brighter than others
// Consts below may be used to equalize these differences
// Note: these values are set from the makefile
const float led_g = LED_G;
const float led_y = LED_Y;
const float led_r = LED_R;
const float led_b = LED_B;

std::vector<float> led_pwm_multipliers = {led_y, led_g, led_g, led_g, led_g,
						led_r, led_y, led_g, led_g, led_g,
						led_g, led_g, led_y, led_r, led_r, led_b};

// "Gamma" correction for LEDs
// This constant is in use by the led_linear() function below.
// This is not the actual "gamma" correction, but something similar.
const float led_gamma = LED_GAMMA;

//================================== GLOBALS ===================================

// Variables holding measurement results
// Numeric arguments are time constants of low pass filters [in seconds]
// Bigger values will further smooth (and slow down) the response.
floatLP cpu(0.5, refresh_rate);
floatLP ram(0.5, refresh_rate);
floatLP temp(0.5, refresh_rate);
float   user;

// pwm_data contains data for PWM() thread to work on
// Each vector item contains 16 bits to be passed to LED driver.
// Vector items are ordered from the least to most significant bits
// in terms of PWM modulation.
// pwm_data_mutex protects pwm_data
typedef std::vector<std::bitset<16>> pwm_data_datatype;
pwm_data_datatype pwm_data;
std::mutex pwm_data_mutex;

// Precalculated PWM periods
// To be filled by PWM thread
std::vector<std::chrono::microseconds> pwm_periods;

// Bools signaling the respective threads to stop
bool pwm_closing = 0;
bool main_closing = 0;


//============================== LED LINEARIZATION =============================

float led_linear(float in) {
	// A LED linearization algorithm that takes a brightness value (0-1)
	// and returns duty cycle (also 0-1).
	// Uses constant "gamma" declared above

	float a = 1 / (std::exp(led_gamma) - 1);
	return a * (std::exp(led_gamma*in) - 1);
}


//================================ shared-memory ===============================

// Shared-memory region
#define SHR_MEM_PATH "/pistackmond"
void *shrmap;
const off_t SHR_MEM_SIZE = sizeof(float);

int openShrMem(int oflags) {
	int rc;
	int fd;

	// get shared memory file descriptor
	fd = shm_open(SHR_MEM_PATH,oflags,S_IRUSR|S_IWUSR);
	if (fd == -1) {
		perror("shm_open failed");
		return -1;
	}
	// works only after shm_open, since shm_open respects umask
	fchmod(fd,S_IRUSR|S_IWUSR|S_IRGRP|S_IWGRP|S_IROTH|S_IWOTH);

	// increase the size if in create-mode
	if (oflags & O_CREAT) {
		rc = ftruncate(fd,SHR_MEM_SIZE);
		if (rc == -1) {
			perror("ftruncate failed");
			shm_unlink(SHR_MEM_PATH);
			return -1;
		}
	}

	// map shared memory
	if (oflags & O_RDWR) {
		shrmap = mmap(NULL,SHR_MEM_SIZE,PROT_WRITE,MAP_SHARED,fd,0);
	} else {
		shrmap = mmap(NULL,SHR_MEM_SIZE,PROT_READ,MAP_SHARED,fd,0);
	}
	close(fd);
	return 0;
}

// read float from shared memory
inline float readShrMem() {
	float value;
	memcpy(&value,shrmap,sizeof(float));
	return value;
}

// this writes a string (cmdline-arg) as float
inline void writeShrMem(std::string str) {
	float value = std::stof(str);
	if (value > 1) value = 1;
	if (value < 0) value = 0;
	memcpy(shrmap,&value,sizeof(float));
}

void closeShrMem(bool unlink=false) {
	munmap(shrmap,SHR_MEM_SIZE);
	if (unlink) {
		shm_unlink(SHR_MEM_PATH);
	}
}

//================================ getopt ======================================

std::string arg_cmd = "";
std::string arg_user = "";
std::string arg_brightness = "";
bool arg_service = false;

void help(char* pgm) {
	std::cerr << "usage: " << pgm << " -u USER_LED" << std::endl <<
	  "where USER_LED is the brightness of a blue user LED on PiStackMon Lite (range: 0-1)" << std::endl <<
	  "For more advanced options see README.md" << std::endl;
	exit(3);
}

void parseArgs(int argc, char*argv[]) {
	int c;
	opterr = 0;

	while ((c = getopt (argc,argv,"sb:u:h")) != -1) {
		switch (c) {
			case 's':
			arg_service = true;
			break;
		case 'b':
			arg_brightness = std::string(optarg);
			break;
		case 'u':
			arg_user = std::string(optarg);
			break;
		case 'h':
	  		help(argv[0]);
	  		break;
		case '?':
			if (optopt == 'b' || optopt == 'u') {
				std::cerr << "error: option -" << optopt << 
				  " requires an argument" << std::endl;
				help(argv[0]);
			} else {
				std::cerr << "error: unknown option -" << 
				  optopt << std::endl;
				help(argv[0]);
				break;
			}
		default:
			help(argv[0]);
		}
	}
	if (optind < argc) {
		arg_cmd = argv[optind];
	}
}

//=================================== MISC =====================================

std::vector<long int> getIntsFromLine(std::string s) {
	// Returns all integers found in a given string

	std::string temp_s;
	long int temp_i;
	std::stringstream ss;
	std::vector<long int> output;

	ss << s;

	// Reading values from ss one by one, and discarding those that
	// cannot be converted to int.
	while (!ss.eof()) {
		ss >> temp_s;
		if (std::stringstream(temp_s) >> temp_i) {
			output.push_back(temp_i);
		}
	}
	return output;
}

//================================ DATA SOURCES ================================

float fetchTemp() {
	// Returns CPU temperature in degrees C

	const std::string temp_file_name = 
			"/sys/devices/virtual/thermal/thermal_zone0/temp";

	std::ifstream temp_file(temp_file_name);

	if(!temp_file.is_open()) {
          	std::fprintf(stderr,"Unable to open %s.\n",
						temp_file_name.c_str());
		return -1.0;
	}

	float result;
	temp_file >> result;
	temp_file.close();
	result /= 1000;
	return result;	
}

//------------------------------------------------------------------------------

float fetchCpu() {
	// Returns CPU load in %.
	// It's a mean value for all cores,
	// and a mean value since the last call of this method.
	// 
	// /proc/stat contains counters of CPU time dedicated to various tasks.
	// Fourth column is the CPU idle time.
	// This function computes how much time CPUs were *not* idle.
	//
	// Too frequent calling (< 50ms) yields results with poor resolution,
	// due to kernel counters working typically at 100Hz.
	// It is recommended to apply some sort of low-pass filter
	// for more meaningful long-term results.

	static std::vector<long int> last_stat;
	std::vector<long int> current_stat;
	int temp_i = 0;
	std::string temp_s;

repeat:

	std::ifstream cpu_file("/proc/stat");
	if(!cpu_file.is_open()) {
          	std::fprintf(stderr,"Unable to open /proc/stat. Quitting!\n");
		exit(-1);
	}

	getline(cpu_file, temp_s);
	cpu_file.close();
	current_stat = getIntsFromLine(temp_s);

	// On first run, the last_stat vector is empty,
	// so it needs to be populated by repeating the whole thing.
	if (last_stat.empty()) {
		last_stat = current_stat;
		std::this_thread::sleep_for(50ms);	
		goto repeat;
	}

	float result = 0;
	for (auto item : current_stat) temp_i+= item;
	for (auto item : last_stat) temp_i-= item;
	
	// This might happen if called too soon after last call
	// The result would be division by zero - nan.
	if (temp_i == 0) {
		std::this_thread::sleep_for(50ms);	
		goto repeat;
	}
	
	// The fourth column represents CPU idle time
	result = current_stat.at(3) - last_stat.at(3);
	result /= temp_i;
	result = 1 - result;
	result *= 100;

	last_stat = current_stat;
	return result;	
}

//------------------------------------------------------------------------------

float fetchRam() {
	// Returns percentage of used RAM.
	// Used memory estimated just like "free" does:
	// MemTotal - MemFree - Buffers - Cached - SReclaimable
	// See "man free" for details.
	
	int memtotal = 1;

	std::string temp_s;
	float result = 0;


	std::ifstream mem_file("/proc/meminfo");
	if(!mem_file.is_open()) {
          	std::fprintf(stderr,"Unable to open /proc/meminfo. Quitting!\n");
		exit(-1);
	}

	while (!mem_file.eof()) {
		getline(mem_file, temp_s);
		//TODO: Replace with "starts_with" when it gets around)
		if 	(temp_s.find("MemTotal:") == 0)
			memtotal = getIntsFromLine(temp_s).at(0);
		else if	(temp_s.find("MemFree:") == 0)
			result -= getIntsFromLine(temp_s).at(0);
		else if	(temp_s.find("Buffers:") == 0)
			result -= getIntsFromLine(temp_s).at(0);
		else if	(temp_s.find("Cached:") == 0)
			result -= getIntsFromLine(temp_s).at(0);
		else if	(temp_s.find("SReclaimable:") == 0)
			result -= getIntsFromLine(temp_s).at(0);
	}
	mem_file.close();

	result /= memtotal;
	result += 1;
	result *= 100;
	return result;
}

inline float fetchUser() {
	// read user-value from shared-memory
	return readShrMem();
}

// ================================ LED DRIVING ================================

std::vector<float> led_pwms() {
	// converts fetched numbers into float PWM values of each LED
	// Includes LED PWM multipliers (for intensity correcton or whatever)
	// Also includes gamma correction
	
	std::vector<float> output(16);

	for (int i=0; i<5; i++) {
		if (cpu.f() >= 20*(i+1)) output[cpu_layout[i]] = 1;
		else {
			output[cpu_layout[i]] = led_linear((cpu.f() - (20*i))/20);
			break;
		}
	}

	for (int i=0; i<5; i++) {
		if (ram.f() >= 20*(i+1)) output[ram_layout[i]] = 1;
		else {
			output[ram_layout[i]] = led_linear((ram.f() - (20*i))/20);
			break;
		}
	}
	if (temp.f() > 40) {
		for (int i=0; i<5; i++) {
			if (temp.f() >= 10*(i+1)+40) output[temp_layout[i]] = 1;
			else {
				output[temp_layout[i]] = led_linear((temp.f() - (10*i+40))/10);
				break;
			}
		}
	}

	output[user_layout[0]] = led_linear(user);
	for (int i=0; i<16; i++) output[i] *= led_pwm_multipliers[i];

	return output;
}

//  -   -   -   -   -   -   -   -   -   -   -   -   -   -   -   -   -   -   -   

pwm_data_datatype format_pwms(std::vector<float> pwms) {
	// Converts float pwms of each LED into a vector of bitsets.
	
	std::vector<std::bitset<pwm_res>> pwms_digitized;
	pwm_data_datatype output;
	std::bitset<16> temp_data;

	for (auto f : pwms) {
		pwms_digitized.push_back(static_cast<uint16_t>(f*(std::pow(2,pwm_res)-1)));
	}
	for (int i=0; i < pwm_res; i++) {
		temp_data.reset();
		for (int j = 0; j < 16; j++) {
			temp_data[j] = pwms_digitized[j][i];
		}
		output.push_back(temp_data);
	}
	return output;

}

//  -   -   -   -   -   -   -   -   -   -   -   -   -   -   -   -   -   -   -   

void sendFrame16(std::bitset<16> f) {
	// Sends data to LED driver chip but does not latch it
	for(int i = 0; i < 16; i++) {
		__sync_synchronize();
		gpioClear(PIN_CLK);
		if (f[15-i]) {
                	gpioSet(PIN_DATA);
		} else {
                	gpioClear(PIN_DATA);
		}
		__sync_synchronize();
		gpioSet(PIN_CLK);
	}
}

//  -   -   -   -   -   -   -   -   -   -   -   -   -   -   -   -   -   -   -   

inline void commitFrame() {
	// Applies latch pulse to LED driver chip
	// Thus applying whatever has been previously sent to it
	// Keeping these separated helps synchronise PWM more precisely

	__sync_synchronize();
	gpioSet(PIN_LATCH);
	__sync_synchronize();
	gpioClear(PIN_LATCH);
	__sync_synchronize();
}

//  -   -   -   -   -   -   -   -   -   -   -   -   -   -   -   -   -   -   -   

void gpioInit() {
	gpioInitImpl();     // platform-specific implementation
	sendFrame16(0);     // clear all LEDs
	commitFrame();
}

//  -   -   -   -   -   -   -   -   -   -   -   -   -   -   -   -   -   -   -   

void setLedState(bool state = true) {
	__sync_synchronize();
	if (state) {
		gpioClear(PIN_BLANK);
        } else {
		gpioSet(PIN_BLANK);
        }
	__sync_synchronize();
}

//  -   -   -   -   -   -   -   -   -   -   -   -   -   -   -   -   -   -   -

void gpioDeinit(bool noclear = false) {

	if (!noclear) {
		sendFrame16(0);		// Turn all them LEDs off
		commitFrame();
	}
	gpioDeinitImpl();
}

//  -   -   -   -   -   -   -   -   -   -   -   -   -   -   -   -   -   -   -   

void PWM() {
	// This is a process intended to run as a separate thread
	// for the sake of simplicity. Really.
	// It reads pwm_data and executes whatever is in there.
	// In order to kill this thread gracefully, set "pwm_closing" to 1. 

	auto next_step = std::chrono::high_resolution_clock::now();
	pwm_data_datatype local_pwm_data;

	gpioInit();
	setLedState(true);

	// Compute PWM periods for each bit
	// Every more significant bit gets twice the time of the previous one
	for (int i = 0; i < pwm_res; i++) {
		pwm_periods.push_back(std::chrono::microseconds(
				static_cast<uint32_t>(pwm_lsb_period*std::pow(2,i))));
	}
	
	/*
	// Initial LED test
	for (int i = 0; i < 16; i++) {
		sendFrame16(1 << i);
		commitFrame();
		std::this_thread::sleep_for(150ms);	
	}
	*/

	while (!pwm_closing) {
		if (pwm_data_mutex.try_lock()){
			local_pwm_data = pwm_data;
			pwm_data_mutex.unlock();
		}
		if (local_pwm_data.size() < pwm_res) {	// Avoid segfaults when pwm data not initialized yet
			std::this_thread::sleep_for(100ms);
			continue;
		}
		for (int i = 0; i < pwm_res; i++) {
			next_step += pwm_periods[i];
			// Catch up if this thread is running really late
			// Happens if daemon launches before Pi updates real time clock
			if (next_step < std::chrono::high_resolution_clock::now())
				next_step = std::chrono::high_resolution_clock::now() + pwm_periods[i];
			sendFrame16(local_pwm_data[(i+1)%pwm_res]);
			std::this_thread::sleep_until(next_step);
			commitFrame();
		}
	}

	gpioDeinit();

}

// =================================== MAIN ====================================

void signal_handle(const int s) {
	// Handles a few POSIX signals, asking the process to die gracefully
	
	main_closing = 1;

	if (s){};	// Suppress warning about unused, mandatory parameter
}

//  -   -   -   -   -   -   -   -   -   -   -   -   -   -   -   -   -   -   -   

int main(int argc, char*argv[]) {

	signal (SIGINT, signal_handle);		// Catches SIGINT (ctrl+c)
	signal (SIGTERM, signal_handle);	// Catches SIGTERM

        parseArgs(argc,argv);
	if (arg_cmd == "allon") {
		gpioInit();
		sendFrame16(-1);	// Dirty "all ones" hack
		commitFrame();
                       setLedState(true);
		exit(0);                // test-mode, no gpioDeInit()
	}
	else if (arg_cmd == "alloff") {
		gpioInit();
		setLedState(true);
		exit(0);                // test-mode, no gpioDeInit()
	}
	else if (arg_user != "") {            // expecting a float 0<=x<=1
		if (openShrMem(O_RDWR)) {
			exit(3);
		}
		writeShrMem(arg_user);
		closeShrMem();
		exit(0);
	}
	else if (!arg_service) {  // require explicit -s flag for service
		std::cerr << "error: illegal invocation" << std::endl;
		help(argv[0]);
	}
	if (arg_brightness != "") {      // expecting a float 0<=x<=1
		float value = std::stof(arg_brightness);
		for (int i=0; i<16; i++) {
			led_pwm_multipliers[i] =
				std::min(1.0f,led_pwm_multipliers[i]*value);
		}
	}

	// create shared memory for user-led
	if (openShrMem(O_RDWR|O_CREAT|O_EXCL)) {
		exit(3);
	}

	// An exact time to gather measurement data and update pwm values
	// refresh_rate determines its frequency.
	auto next_refresh = std::chrono::high_resolution_clock::now();
	
	// Create PWM thread
	std::thread pwm_thread (PWM);

	// Assign Real Time priority to PWM thread
	sched_param sch;
	int policy;
	pthread_getschedparam(pwm_thread.native_handle(), &policy, &sch);
	sch.sched_priority = 99;
	pthread_setschedparam(pwm_thread.native_handle(), SCHED_FIFO, &sch);


	float userCache = 0;
	float cpuCache = 0;
	float ramCache = 0;
	float tempCache = 0;
	int divCounter = 0;

	while (!main_closing) {

		if (++divCounter >= ref_div) {
			cpuCache = fetchCpu();
			ramCache = fetchRam();
                        if (tempCache >= 0.0) {
                          // returns -1 if thermal_zone0 is missing
                          tempCache = fetchTemp();
                        }
			divCounter = 0;
		}	
		// Refresh user LED on every cycle, for faster response
		userCache = fetchUser();

		user = userCache;
		cpu = cpuCache;
		ram = ramCache;
		temp = tempCache < 0.0 ? 0.0:tempCache;

		//  -   -   -   -   -   -   -   -   -   -   -   -   -   -   -
	
		pwm_data_mutex.lock();
		pwm_data = format_pwms(led_pwms());
		pwm_data_mutex.unlock();

		//  -   -   -   -   -   -   -   -   -   -   -   -   -   -   -

		next_refresh += refresh_period;
		// Catch up if this thread is running really late
		// Happens if daemon launches before Pi updates real time clock
		if (next_refresh < std::chrono::high_resolution_clock::now())
			next_refresh = std::chrono::high_resolution_clock::now() + refresh_period;
		std::this_thread::sleep_until(next_refresh);	
	}

	pwm_closing = 1;
	pwm_thread.join();
	closeShrMem(true);
	exit(0);
}

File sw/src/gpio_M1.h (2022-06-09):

// -------------------------------------------------------------------------
// GPIO-specific functions
//
// gpio_M1.h: header file for Odroid M1
//
// Website: https://github.com/tomek-szczesny/pistackmon
// Authors: Tomek Szczesny, Bernhard Bablok
// License: GPL3
// -------------------------------------------------------------------------

#ifndef _GPIO_M1_H
#define _GPIO_M1_H

#include <cstdint>

#define PIN_DATA   16
#define PIN_CLK    17
#define PIN_LATCH  106
#define PIN_BLANK  121

extern volatile uint32_t * gpiomap;

void gpioInitImpl();
void gpioDeinitImpl();
void rk_gpio(bool g3, int offset, int bit, bool val);

inline void gpioSet(uint8_t pin) {
	if (pin < 96) 	rk_gpio(0,  pin     / 16,  pin     % 16, 1);
	else 		rk_gpio(1, (pin-96) / 16, (pin-96) % 16, 1);
}

inline void gpioClear(uint8_t pin) {
	if (pin < 96) 	rk_gpio(0,  pin     / 16,  pin     % 16, 0);
	else 		rk_gpio(1, (pin-96) / 16, (pin-96) % 16, 0);
}

#endif

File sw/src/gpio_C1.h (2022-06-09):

// -------------------------------------------------------------------------
// GPIO-specific functions
//
// gpio_C1.h: header file for Odroid C1
//
// Website: https://github.com/tomek-szczesny/pistackmon
// Authors: Tomek Szczesny, Bernhard Bablok
// License: GPL3
// -------------------------------------------------------------------------

#ifndef _GPIO_C1_H
#define _GPIO_C1_H

#include <cstdint>

#define PIN_DATA   88
#define PIN_CLK   116
#define PIN_LATCH 115
#define PIN_BLANK 103

#define OFF_X   0x0D
#define OFF_Y   0x10
#define START_X   97
#define START_Y   80

extern volatile uint32_t * gpiomap;

void gpioInitImpl();
void gpioDeinitImpl();

inline void gpioSet(uint8_t pin) {
	if (pin > START_X) {
		*(gpiomap+OFF_X) |= (1 << (pin-START_X)); // Set pin high
	} else {
		*(gpiomap+OFF_Y) |= (1 << (pin-START_Y)); // Set pin high
	}
}

inline void gpioClear(uint8_t pin) {
	if (pin > START_X) {
		*(gpiomap+OFF_X) &= ~(1 << (pin-START_X)); // Set pin low
	} else {
		*(gpiomap+OFF_Y) &= ~(1 << (pin-START_Y)); // Set pin low
  }
}

#endif

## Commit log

2021-03-02 Initial release - 1.0
    [PiStackMon-B_Cu.gbl, PiStackMon-B_Mask.gbs, PiStackMon-B_Paste.gbp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]
2021-03-03 Improved 3D model of hw, new renders
    [PiStackMon.kicad_pcb]
2021-03-25 Fix for rapid CPU blinking on startup
    [pistackmond.cpp]
2021-03-27 More alt components; JLC assembly component codes
    [PiStackMon.kicad_pcb, PiStackMon.sch]
2021-04-06 Mutex protection of pwm_data (possible fix for std::bad_alloc)
    [pistackmond.cpp]
2021-04-08 Another PWM tweak
2021-04-10 Late RTC sync fix
    The issue was present with my first Pi connected to Internet via WiFi. As the connection is estabilished later in boot time, so is the RTC synced later.
    When the clock was adjusted, the pistackomd's real time process hogged CPU for about 20 minutes to catch up with 50 years worth of sw PWM with no sleep.
    [pistackmond.cpp]
2021-04-29 Cleaned up the fabrication data on PCB
    [PiStackMon.kicad_pcb]
2021-05-06 "allon" and "alloff" LED test modes
2021-05-06 Disabled initial LED test
2021-05-08 Colors of some LEDs changed; More information about adjusting LED currents
    Temperature monitor LEDs have been changed to reflect 70 deg as a warning temperature (yellow), since some RPi models apply soft throttling above 60 deg. Also running Pi at 70 deg and beyond is proba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
    RAM indicator sees color change to green at 60% level, since this is not really a state worth warning just yet.
    More R2 values are provided on the schematic to let the user pick all sorts of LED currents.
    [PiStackMon.sch]
2021-05-08 Updated schematic PDF
2021-06-30 Random segfault fix (Almost certain)
    [pistackmond.cpp]
2021-06-30 Added gerber files for direct manufacturing
2021-11-07 Fix for long uptimes (60+ days)
    [pistackmond.cpp]
2021-11-25 Fix for Rpi regression
    [pistackmond.cpp]
2022-02-08 Moved original pistackmon hw into "classic" subdir
    [PiStackMon-B_Cu.gbl, PiStackMon-B_Mask.gbs, PiStackMon-B_Paste.gbp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]
2022-02-08 Preliminary release of 'lite' hw
    [PiStackMon_lite.kicad_pcb, PiStackMon_lite.kicad_sch, PiStackMon_lite.sch]
2022-02-10 Updating LED driver to TLC59282
    [PiStackMon_lite.kicad_pcb, PiStackMon_lite.kicad_sch]
2022-02-12 Minor changes based on @bablokb's feedback
    [PiStackMon_lite.kicad_pcb, PiStackMon_lite.kicad_sch]
2022-02-13 Adding JLCPCB production files
    [BOM-PiStackMon_lite.csv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]
2022-02-14 syntax fix: removed trailing #endif
    [pistackmond.cpp]
2022-02-21 added *-backups to exclude KiCAD6-backups
2022-02-21 clear LEDs before pulling BLANK down
2022-02-24 replaced type of variable user (float instead of floatLP)
    [pistackmond.cpp]
2022-03-31 Adding pin-table.md to repo
2022-04-05 Bug fixes, now M1 works
    [pistackmond.cpp]
2022-06-04 added variable PCB
2022-06-04 fixes for lite-pcb
2022-06-10 removed definition and use of PCB-variable
2022-06-16 implement user-led control via shared-memory
2022-06-24 link to images of lite and classic pcb
2022-06-25 LED performance tweaks
2022-07-05 Revert "unlink shrmem from signal-handler for pistackmond-service"
    This reverts commit 491d5954197e8289864cbb2f41f7fcfb871be11b.
    [pistackmond.cpp]
2022-07-22 support build-time configuration of LED-brightness
2022-07-22 document makefile argument for LED-brightness
2022-08-14 Resistor values tweak (LEDs were too bright)
    [BOM-PiStackMon_lite.csv, PiStackMon_lite.kicad_sch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]
2022-08-14 New "usage" output; User LED value limited to 0-1
2022-08-14 Adding PSM Lite schematic PDF
